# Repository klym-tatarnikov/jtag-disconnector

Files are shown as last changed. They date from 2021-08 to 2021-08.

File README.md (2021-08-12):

# jtag-disconnector
Debug probe disconnector. <br/>
This adapater designed for power measurement, debug (deep-)sleep and low power modes on battery powered devices such as Bluetooth Low Energy, Zigbee, LoRa, etc.<br />
Normally for measuring power consumption of low power devices debug probe needs to be fully disconnected to exclude all parasitic current sources/sinks. <br />
Switching is carried out using 5V reed relays. Controlled by toggle switch or external trigger. <br />
PIN20 of JTAG connector can be used for powering device as well as to control relays. 

## Schematics
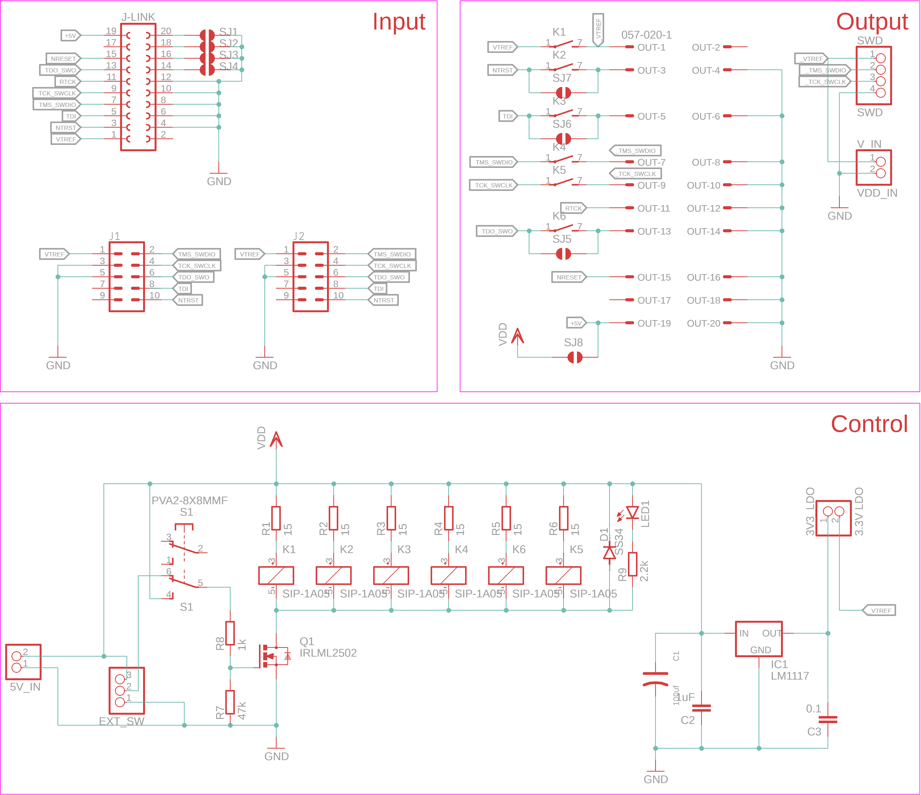
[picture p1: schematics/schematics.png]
Schematics


## J-Link connection
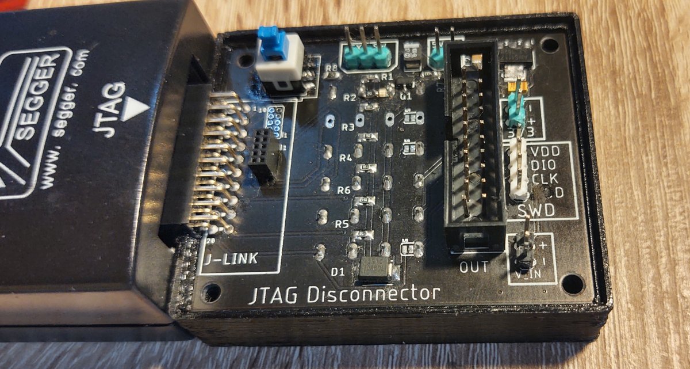
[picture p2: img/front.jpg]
Front


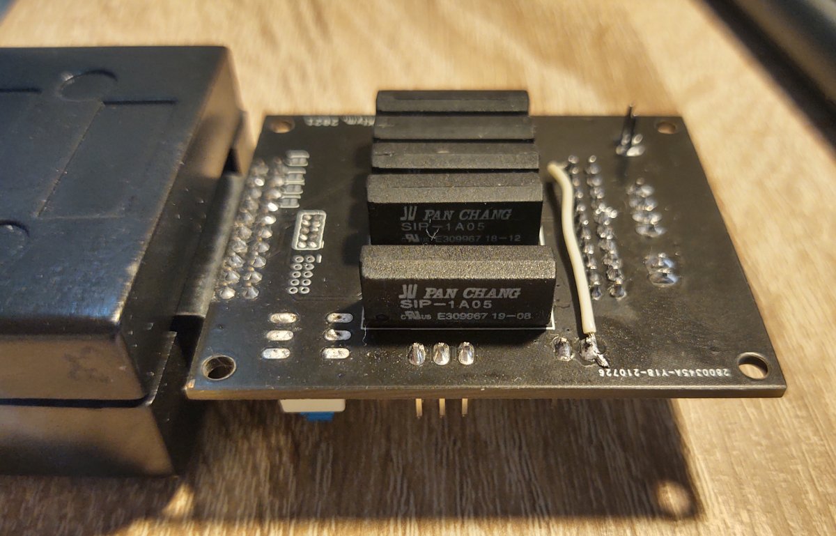
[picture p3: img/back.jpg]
Back


## Segger J_Link EDU-Mini connection
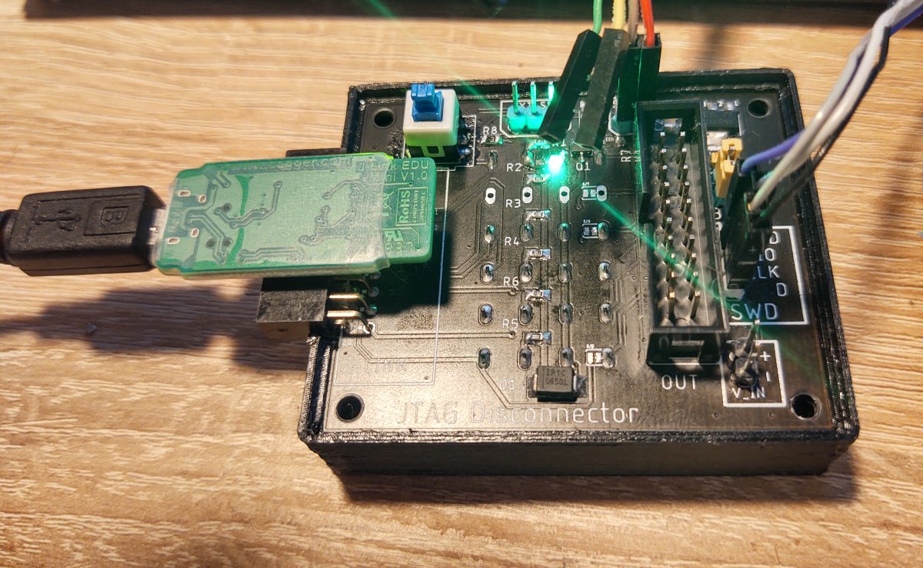
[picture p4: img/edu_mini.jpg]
EDU Mini


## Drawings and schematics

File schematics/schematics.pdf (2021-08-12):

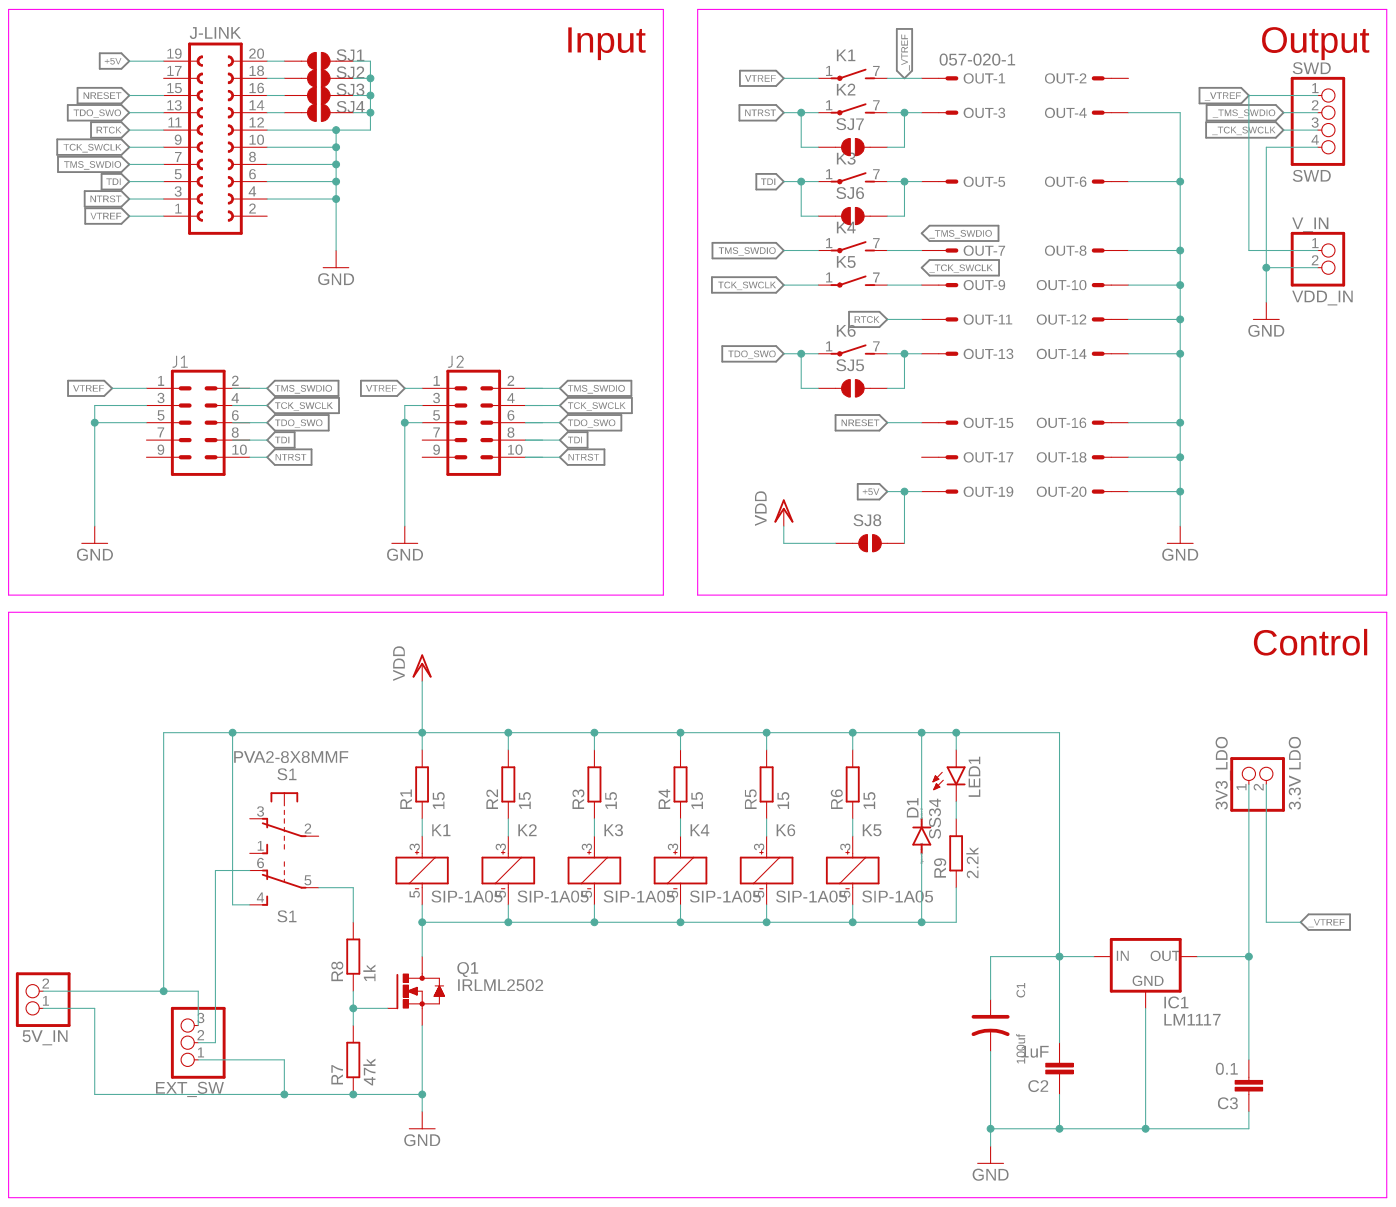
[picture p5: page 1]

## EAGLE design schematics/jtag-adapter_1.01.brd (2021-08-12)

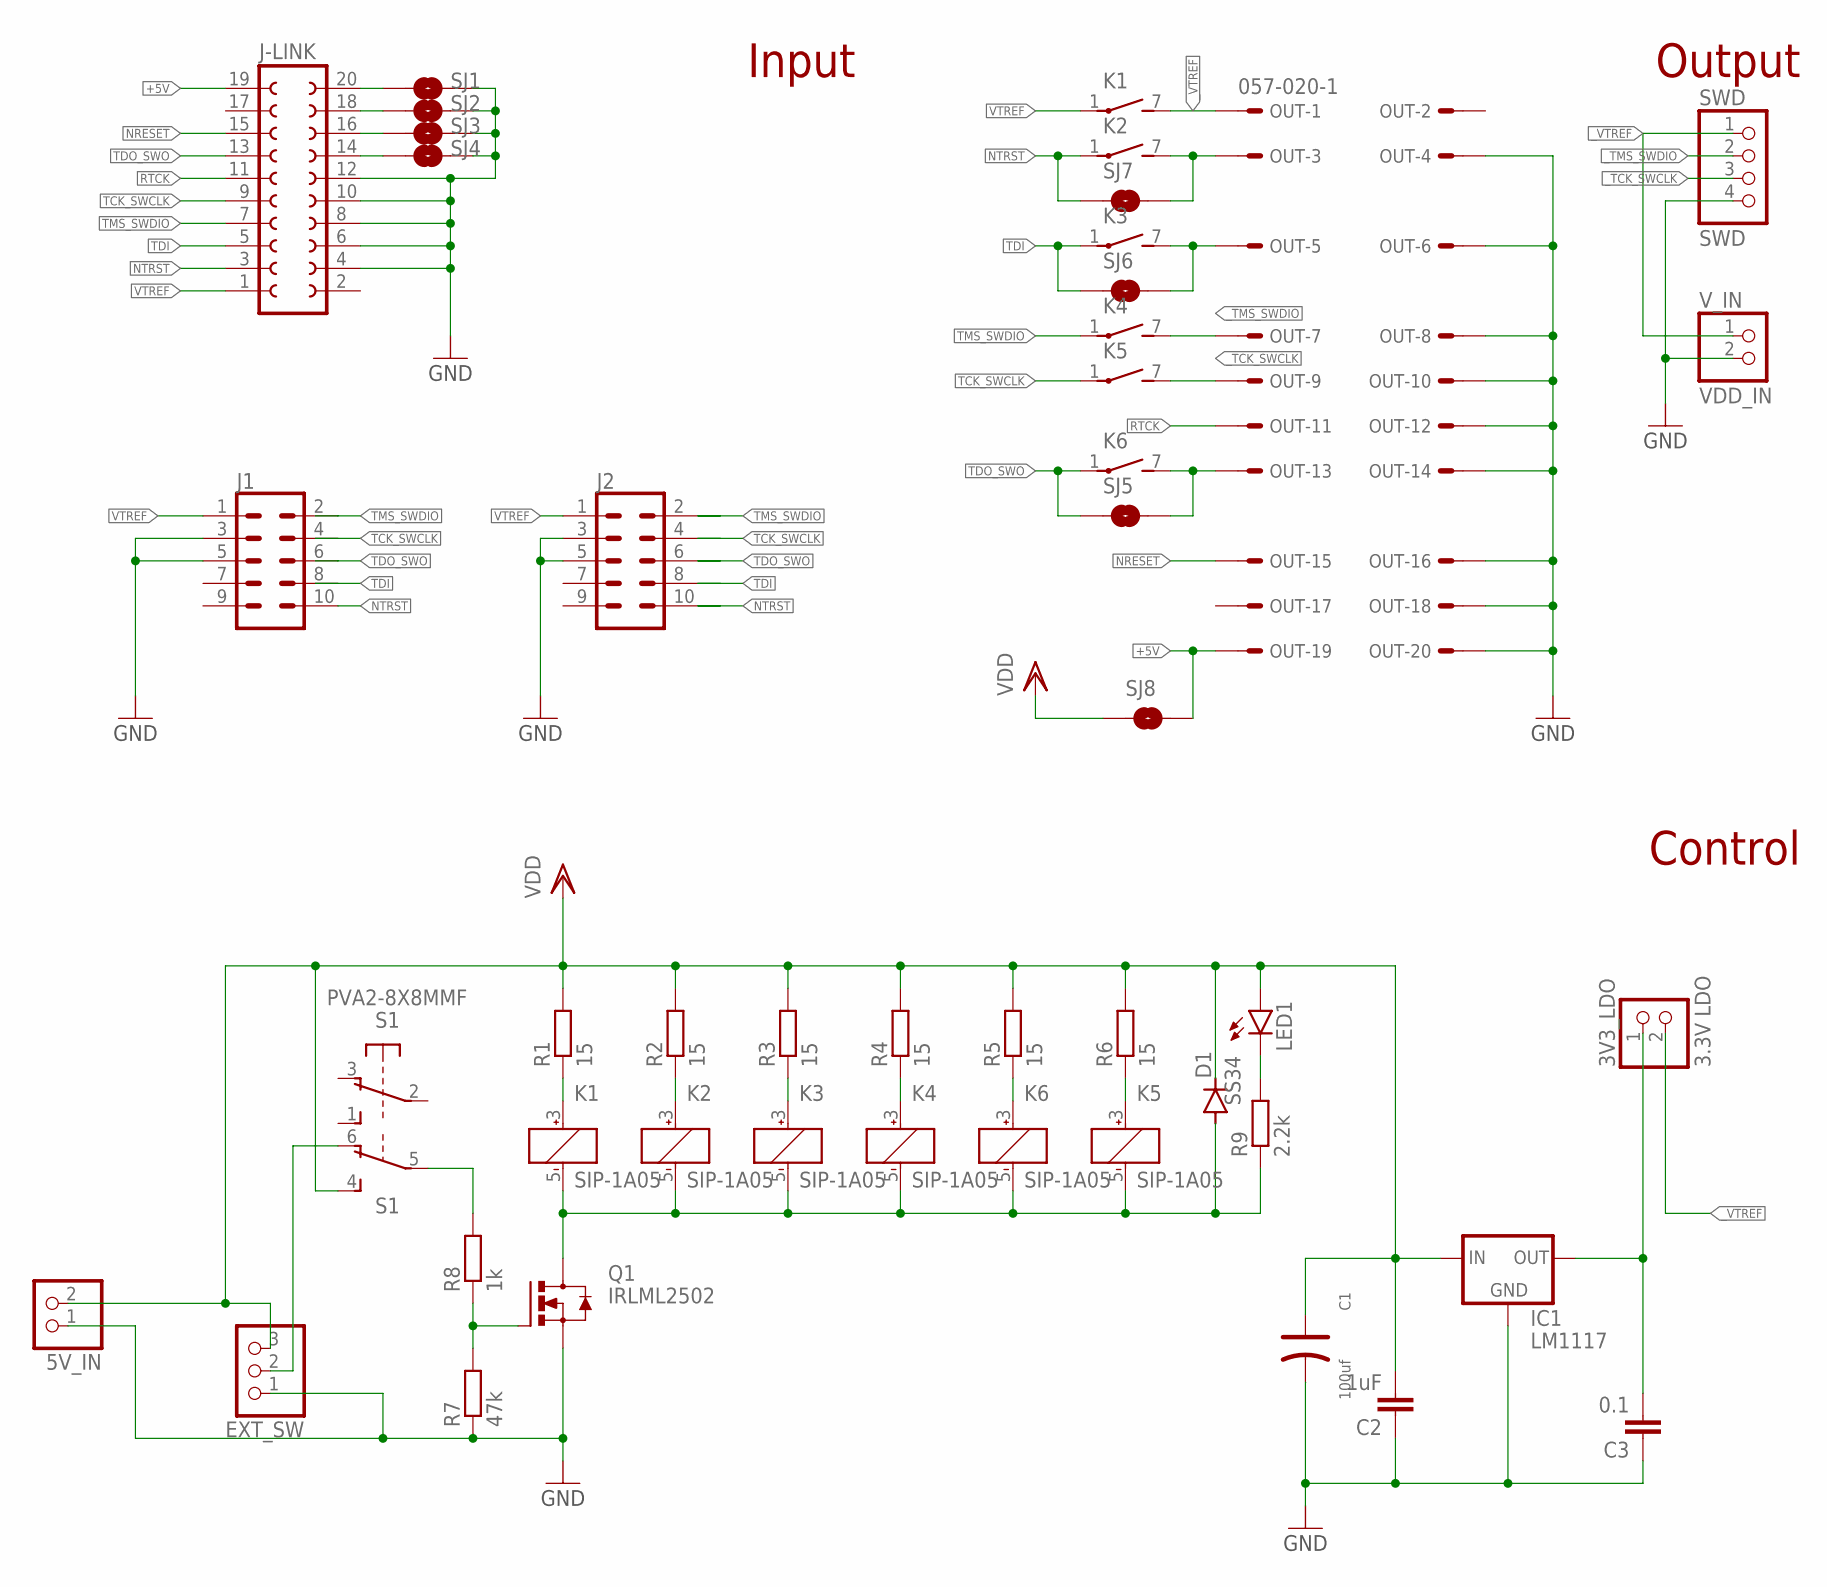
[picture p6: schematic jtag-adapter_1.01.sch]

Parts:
3V3_LDO: 3.3V LDO; 1X02
5V_IN: PINHD-1X2; 1X02
C1: 100uf; AVX-B
C2: 1uF; C1206
C3: 0.1; C1206
D1: SS34; SMB
EXT_SW: PINHD-1X3; 1X03
IC1: LM1117; SOT223
J1, J2: CONN_05X20.05_IN_PTH_SILK; 2X5_PTH_SILK_.05
J-LINK: FE10-2W
K1, K2, K3, K4, K5, K6: SIP-1A05; REED
LED1: LEDCHIP-LED0805; CHIP-LED0805
OUT: 057-020-1
Q1: IRLML2502; SOT23
R1, R2, R3, R4, R5, R6: 15; R0805
R7: 47k; R0805
R8: 1k; R0805
R9: 2.2k; R0805
S1: PVA2-8X8MMF; PVA2F
SJ1, SJ2, SJ3, SJ4, SJ5, SJ6, SJ7, SJ8: SOLDERJUMPERTRACE; SJ_2S-TRACE
SWD: SWD; 1X04
V_IN: VDD_IN; 1X02

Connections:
3V3_OUT: 3V3_LDO.1, C3.2, IC1.2 (OUT)
+5V: J-LINK.19, OUT.19, SJ8.2
GND: 5V_IN.1, C1.-, C2.1, C3.1, EXT_SW.1, IC1.1 (GND), J1.3, J1.5, J2.3, J2.5, J-LINK.4, J-LINK.6, J-LINK.8, J-LINK.10, J-LINK.12, OUT.4, OUT.6, OUT.8, OUT.10, OUT.12, OUT.14, OUT.16, OUT.18, OUT.20, Q1.2 (S), R7.1, SJ1.2, SJ2.2, SJ3.2, SJ4.2, SWD.4, V_IN.2
unnamed: LED1.C, R9.2
unnamed: R8.2, S1.5
unnamed: K2.7 (S), OUT.3, SJ7.2
unnamed: K3.7 (S), OUT.5, SJ6.2
unnamed: EXT_SW.2, S1.6 (O)
unnamed: K6.7 (S), OUT.13, SJ5.2
unnamed: K1.3 (+), R1.1
unnamed: K2.3 (+), R2.1
unnamed: K3.3 (+), R3.1
unnamed: K4.3 (+), R4.1
unnamed: K6.3 (+), R5.1
unnamed: K5.3 (+), R6.1
unnamed: Q1.1 (G), R7.2, R8.1
unnamed: D1.A, K1.5 (-), K2.5 (-), K3.5 (-), K4.5 (-), K5.5 (-), K6.5 (-), Q1.3 (D), R9.1
unnamed: J-LINK.14, SJ4.1
unnamed: J-LINK.16, SJ3.1
unnamed: J-LINK.18, SJ2.1
unnamed: J-LINK.20, SJ1.1
NRESET: J-LINK.15, OUT.15
NTRST: J1.10, J2.10, J-LINK.3, K2.1, SJ7.1
RTCK: J-LINK.11, OUT.11
TCK_SWCLK: J1.4, J2.4, J-LINK.9, K5.1
TDI: J1.8, J2.8, J-LINK.5, K3.1, SJ6.1
TDO_SWO: J1.6, J2.6, J-LINK.13, K6.1, SJ5.1
TMS_SWDIO: J1.2, J2.2, J-LINK.7, K4.1
VDD: 5V_IN.2, C1.+, C2.2, D1.C, EXT_SW.3, IC1.3 (IN), LED1.A, R1.2, R2.2, R3.2, R4.2, R5.2, R6.2, S1.4 (S), SJ8.1
VTREF: J1.1, J2.1, J-LINK.1, K1.1
_TCK_SWCLK: K5.7 (S), OUT.9, SWD.3
_TMS_SWDIO: K4.7 (S), OUT.7, SWD.2
_VTREF: 3V3_LDO.2, K1.7 (S), OUT.1, SWD.1, V_IN.1

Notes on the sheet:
Input
Output
Control

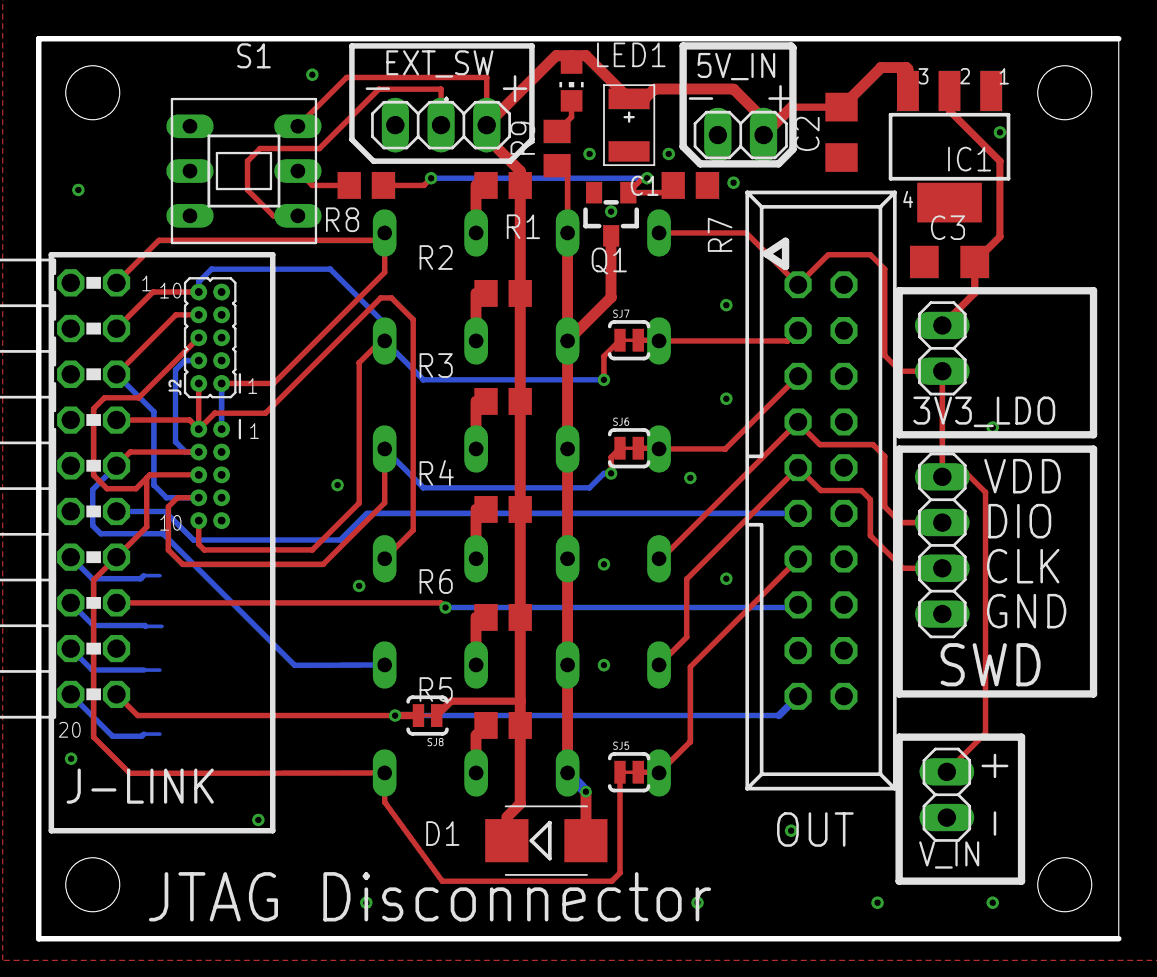
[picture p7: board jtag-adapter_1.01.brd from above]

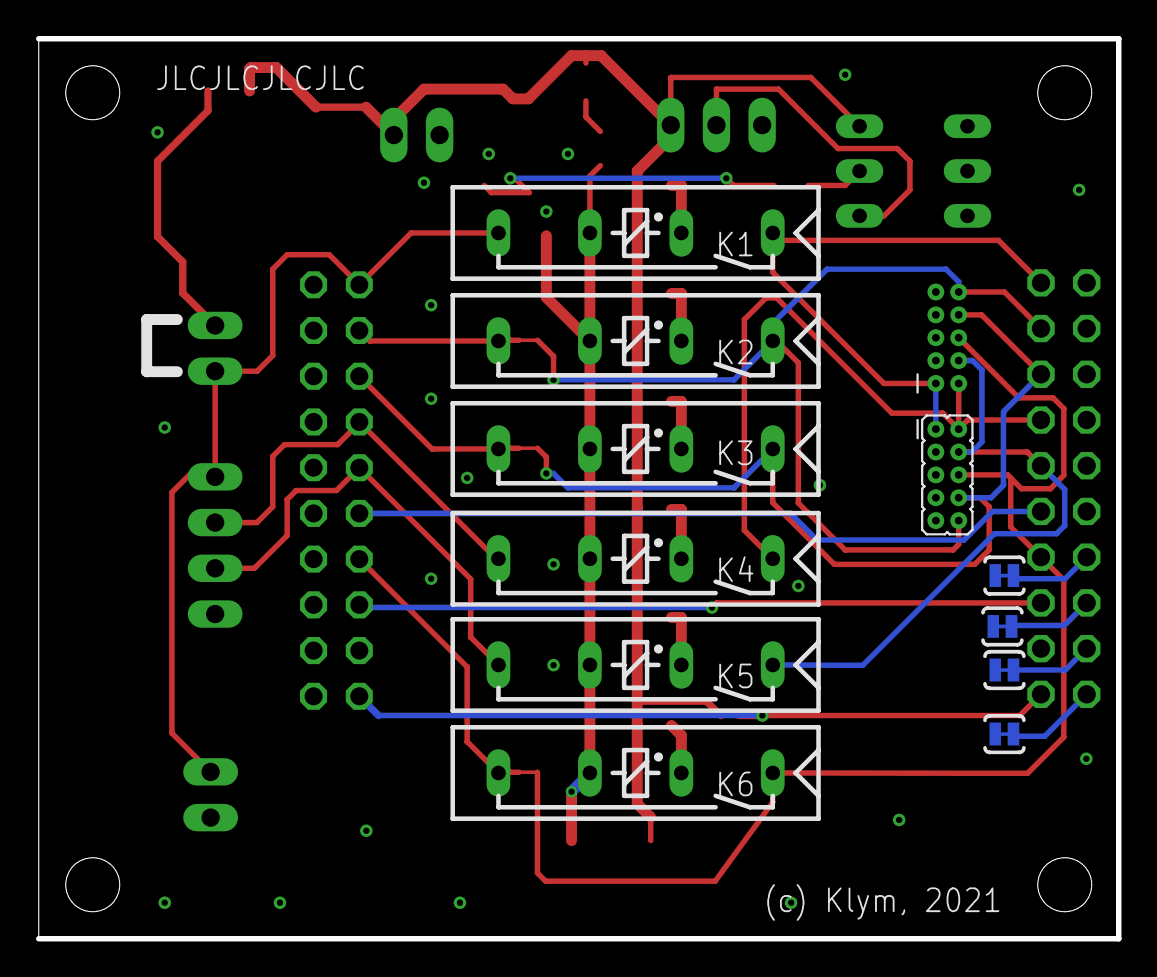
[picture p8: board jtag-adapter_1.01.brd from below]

Board: 2 copper layers, 60.0 x 50.0 mm, 40 parts (11 on the bottom side), 33 nets.

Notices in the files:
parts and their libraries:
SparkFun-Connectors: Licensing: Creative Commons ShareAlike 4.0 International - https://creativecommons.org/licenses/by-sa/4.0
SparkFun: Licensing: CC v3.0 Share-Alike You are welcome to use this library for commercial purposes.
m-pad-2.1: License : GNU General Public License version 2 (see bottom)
